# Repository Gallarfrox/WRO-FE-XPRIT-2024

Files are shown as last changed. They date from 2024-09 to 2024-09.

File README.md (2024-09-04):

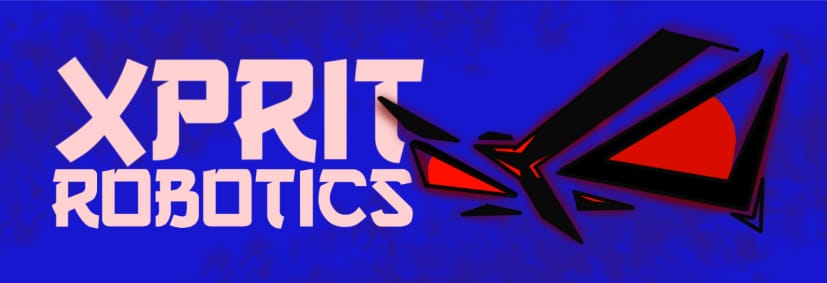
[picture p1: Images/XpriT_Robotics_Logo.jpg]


## Introduction
We are a team from Argentina participating in the Future Engineer Category at the World Robot Olympiad (WRO). Our team, XpriT Robotics, is composed of Franco Gallardo and Nahuel Cabaña.
## Index
* [**Contents**](#Contents)
* [**Chassis**](#Chassis)
* [**Power Supply**](#Power_Supply)
* [**Mobility And Direction**](#Mobility_And_Direction)
* [**Electronic Schematics**](#Schematic)
* [**Team Photos**](#Photos)
* [**Demonstration Videos**](#Demonstration_Videos)
## Contents
 * `3D Design` Contains 3D models of the robot in .STL format, ready for 3D printing.
 * `Edge Impulse` Includes obstacle images captured with the ESP32 Cam for training the machine learning model using Edge Impulse.
 * `SRC` Folder with all source codes and electronic schematics of the robot.
 * `Images` Robot photos and logos
 * `Youtube Channel` Videos demonstrating the robot navigating the circuit and avoiding obstacles.

## Chassis
 
 The Chassis of our robot are 3D printed Parts that were designed using SolidWorks and Tinkercad. All 3D models are in [**3D design Folder.**](https://github.com/Gallarfrox/WRO-FE-XPRIT-2024/tree/8289e319c8ed50b18eef6a841f7b57f9364190d7/3D%20Desings)
## Power Supply

The power supply utilized is a 370mAh 11.1V Li-Po battery. Additionally, we employ an LM7805 voltage regulator to stabilize the power supplied to our boards and microcontrollers.
## Mobility And Direction

To control direction, 
Our robot is designed with one DC motor and a single servo motor, chosen for their ease of replacement in Argentina also for its easy implementation. We use a custom 3D-printed part to enhance the steering of the front wheels, using the Ackerman Method for optimal maneuverability. The two wheels are directly attached to the DC motor, creating a compact and agile design. The robot follows the circuit’s external walls, ensuring an optimal turning radius and quick response time.
## Electronic Schematics

Our Electronic Schematics and Codes we use are in [**SRC folder.**](https://github.com/Gallarfrox/WRO-FE-XPRIT-2024/tree/fe686a653da6ce5ed55e57e9bf3dd3e55d9c889c/SRC)
## Team Photos

### Photo:
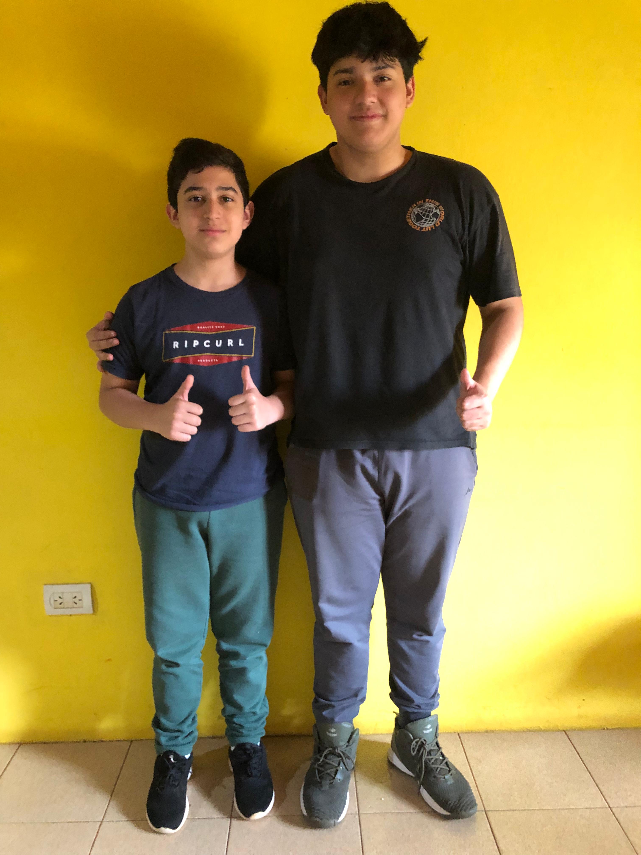
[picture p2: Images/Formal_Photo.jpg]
OPhoto

We have a funny photo in [**Images Folder**](https://github.com/Gallarfrox/WRO-FE-XPRIT-2024/tree/f97b17c5f60459615c8f3205b750cb3410c85aa1/Images)

## Demonstration Videos

Vist to [**this youtube channel**](https://youtube.com/@xprit_robotics?si=dhm_ktdyuf9bD-lI) to see demostration videos of the robot working on the circuit

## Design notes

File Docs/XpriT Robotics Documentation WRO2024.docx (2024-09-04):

# WORLD ROBOT OLYMPIAD 2024

# 2018

Future Engiener

Participants: Cabaña Nahuel, Gallardo Franco

Mentor: Aguirre Franco

Country: Argentina

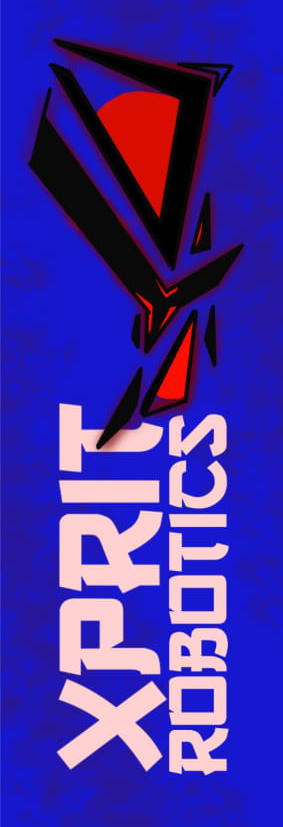
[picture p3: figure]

## Mobility Management

In alignment with the competition regulations, our robot is designed with precision, utilizing one DC motor and a single servo motor. To optimize the steering system, we have ingeniously incorporated a custom 3D-printed component that facilitates the turning of both front wheels, enabling smooth transitions from left to right. This steering mechanism, while straightforward in its design, proves to be highly effective and reliable for the robot's maneuverability.

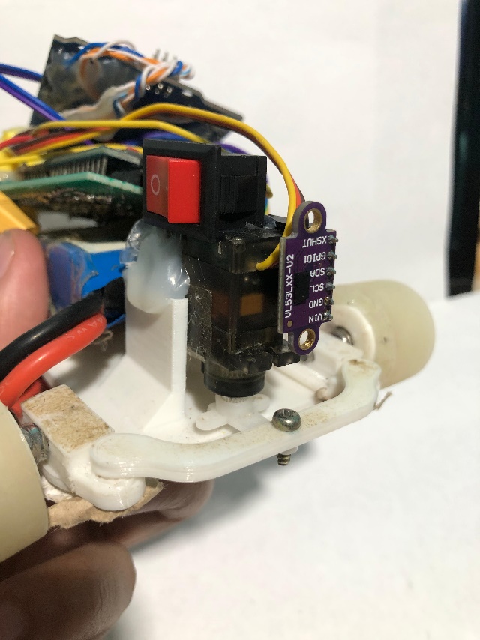
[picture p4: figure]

The DC motor is strategically mounted to ensure maximum efficiency. We've directly attached two wheels to it, achieving a streamlined and compact build. This not only minimizes the robot's overall size but also enhances its agility and responsiveness. The DC motor is critical in providing the essential forward and backward movements, making the robot versatile and well-suited for various challenges posed by the competition.

## Power and Sense Management

We power our robot using a 7V 2000mAh Li-Po battery, which efficiently drives both the logic components and the DC motors. Li-Po (Lithium-Polymer) batteries are particularly well-suited for robotics due to their lightweight design and high energy density, offering an excellent balance between power and portability. This allows the robot to maintain peak performance without adding unnecessary weight, which is crucial in competitive environments where every gram counts.

In terms of sensor technology, our robot is equipped with three CJVL53L0XV2 sensors, which play a critical role in ensuring precise and rapid wall distance detection. These sensors are capable of measuring distances up to 2 meters with millimeter-level accuracy, providing reliable data that allows our robot to navigate its environment with exceptional precision.

The high resolution of these sensors ensures that even the smallest deviations from the intended path are detected and corrected in real-time, enhancing the robot’s ability to respond to dynamic conditions and maintain optimal performance throughout the competition.

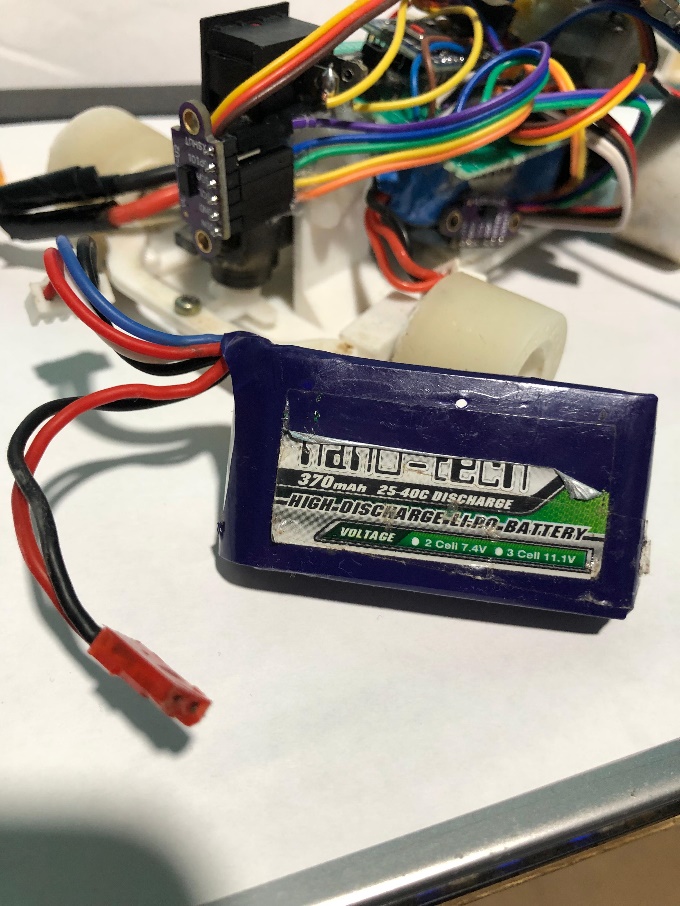
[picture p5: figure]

## Obstacle Management

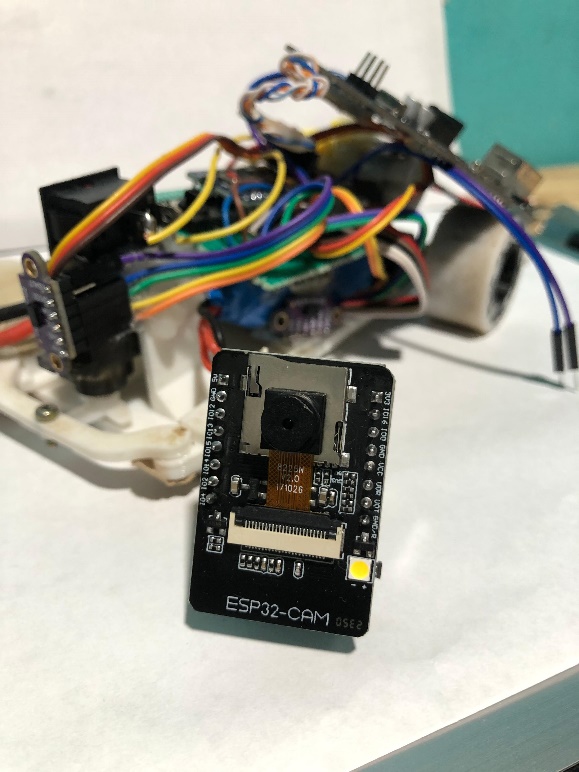
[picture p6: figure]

To detect colors and obstacles, we utilize an ESP32 camera, a versatile board that excels not only in capturing images but also in processing them using artificial intelligence (AI). This capability makes the ESP32 camera particularly effective for real-time obstacle avoidance, as it enables the robot to make instantaneous decisions based on its environment. The onboard processing power of the ESP32 allows it to handle complex computations directly on the device, thereby eliminating the latency associated with sending data to an external server. This local processing capability ensures faster and more efficient responses, which is critical in dynamic and fast-paced competition settings where every millisecond counts.

In order to optimize the performance of the ESP32 camera, we train its system using Edge Impulse, a cutting-edge platform that streamlines the creation and training of custom machine learning models. Edge Impulse allows us to develop models tailored to our specific needs, enabling the camera to recognize and differentiate between a wide range of colors and objects with high accuracy. By leveraging this platform, we significantly enhance the robot's ability to identify and avoid obstacles in real-time, ensuring that it can navigate complex environments with precision and reliability. This integration of advanced AI and machine learning techniques into our robot's sensory system represents a significant advantage, providing it with the intelligence necessary to adapt to changing conditions and make informed decisions on the fly.

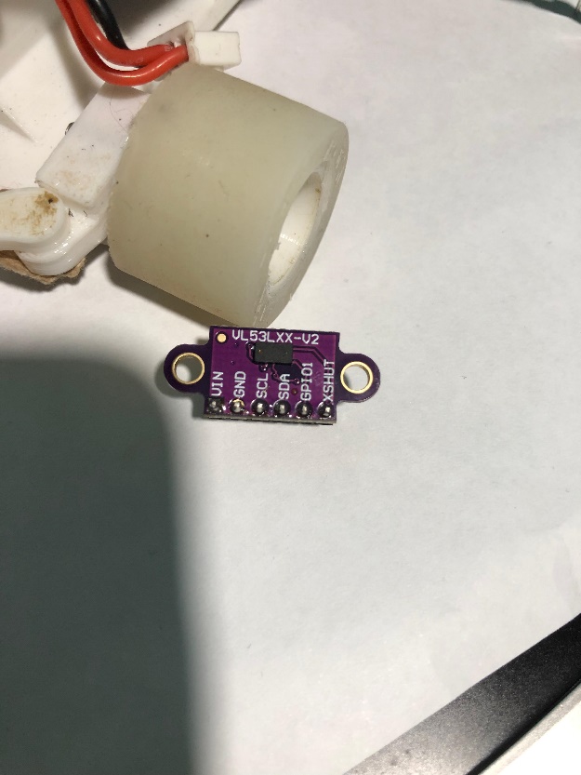
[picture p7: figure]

GitHub

We use GitHub as our version control system, which allows us to efficiently manage and track changes in our code. Additionally, we use it for file sharing among team members and to keep our project documentation up to date, ensuring everyone has access to the latest information and resources.

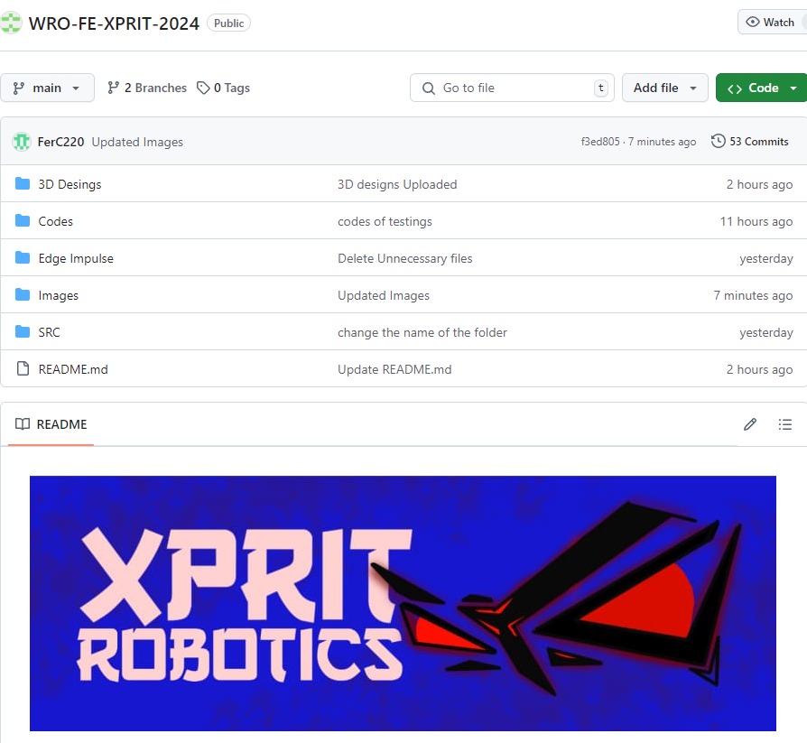
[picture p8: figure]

Engineering Factor

The robot's chassis and all of its mechanisms were designed and 3D-printed by us. The steering system was designed using the Ackerman method. The control board and its circuit were also designed, soldered, and engineered by us.

We use two ESP32-C3 Super Mini controllers: one as the master, which reads sensors and performs calculations to control the robot, and a second as the slave, which receives movement commands. This second controller manages the DC motor and the servo motor based on the information sent by the master.

Additionally, we use CJVL53L0XV2 sensors to provide the robot with spatial awareness, allowing it to detect its surroundings and complete the challenge.

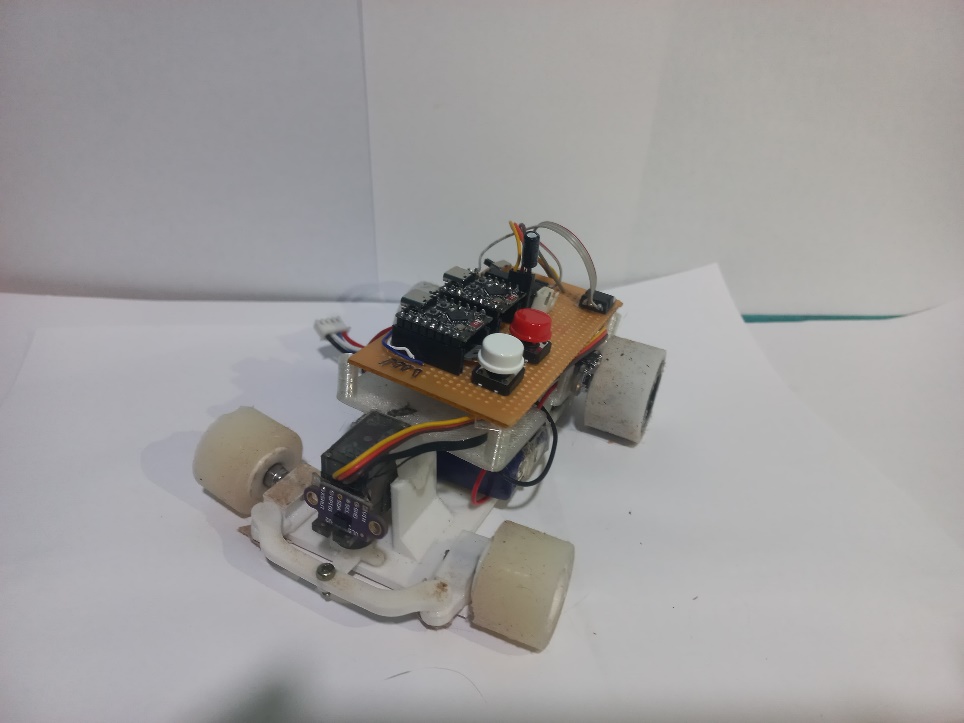
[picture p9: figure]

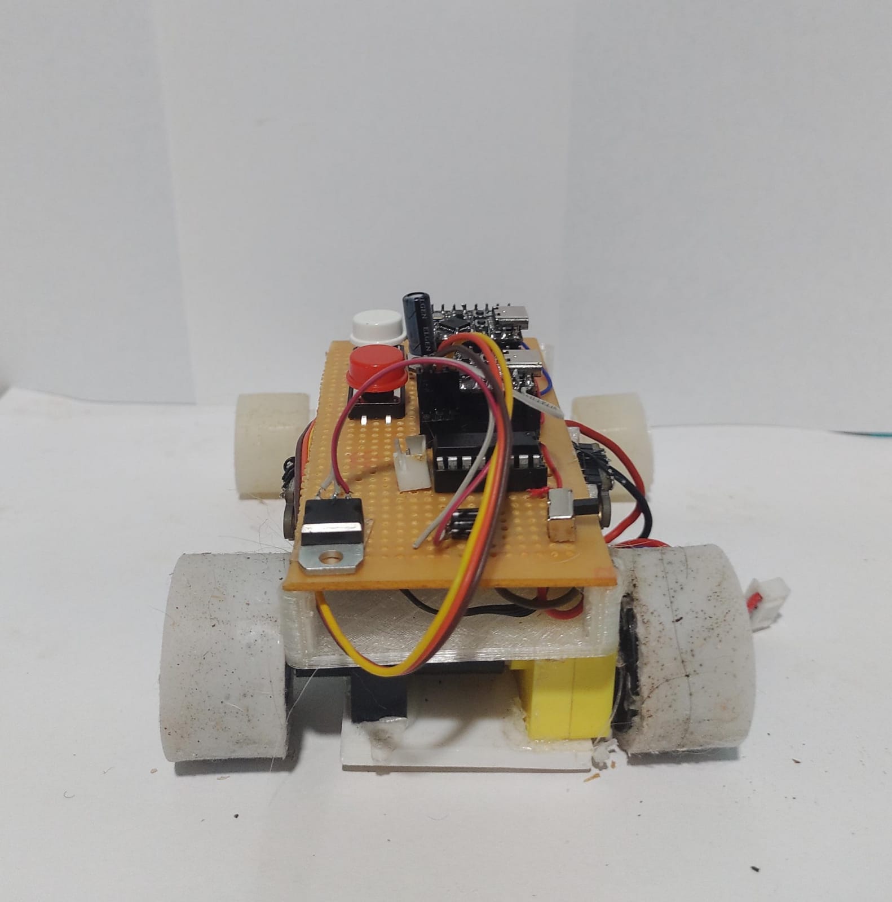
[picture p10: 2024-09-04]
Images/Back_side_Robot.jpg

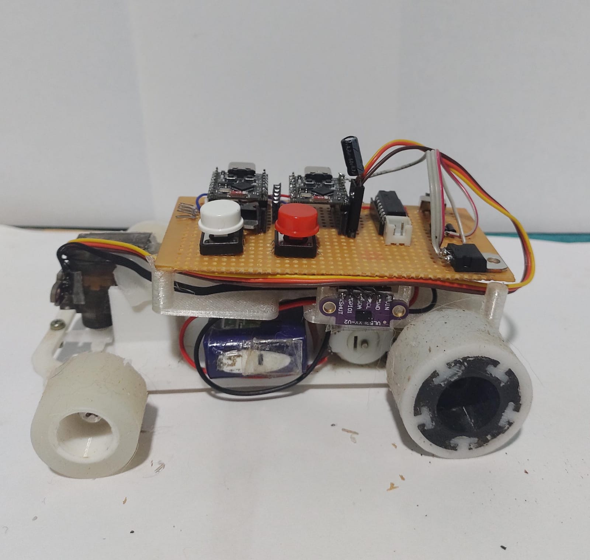
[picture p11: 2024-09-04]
Images/Left_side_robot.jpg

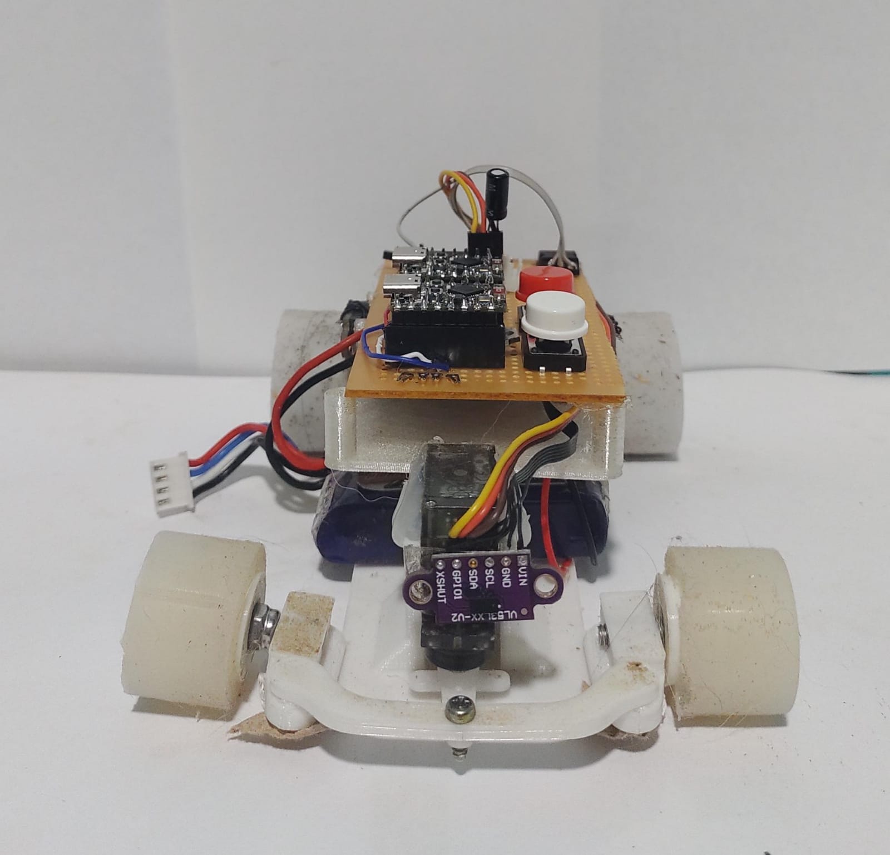
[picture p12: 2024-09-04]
Images/Front_side_Robot.jpg

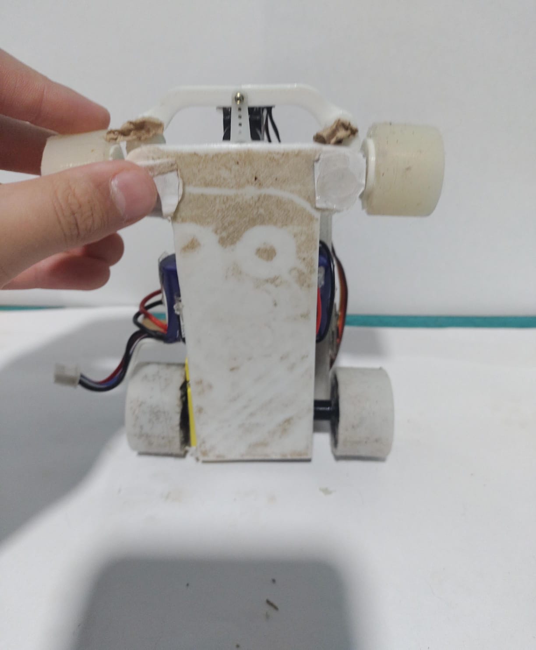
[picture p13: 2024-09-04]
Images/Bottom_side_robot.jpg

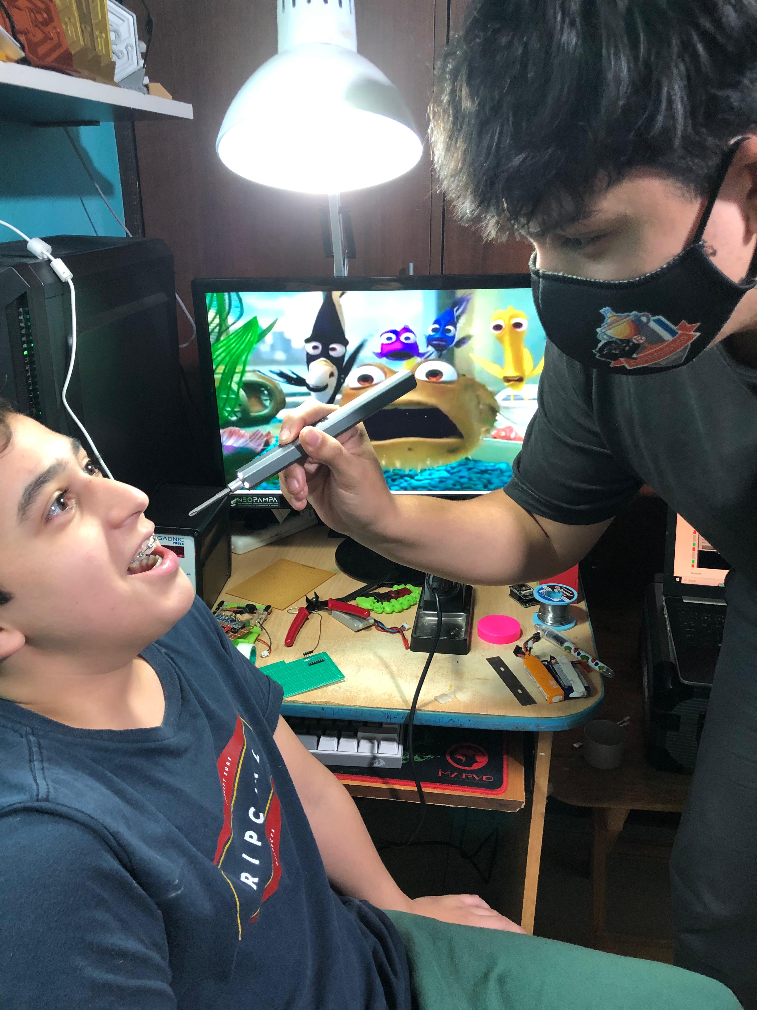
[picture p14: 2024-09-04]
Images/Funny_Photo.jpg

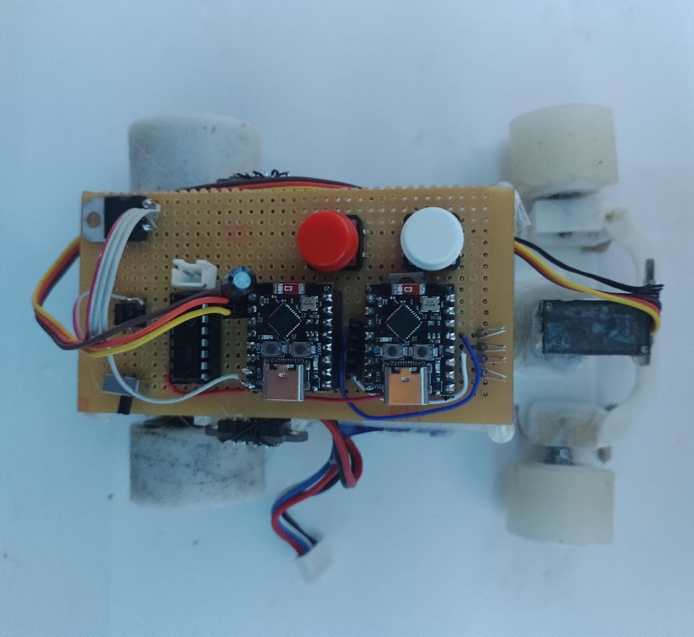
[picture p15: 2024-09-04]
Images/Top_side_robot.jpg

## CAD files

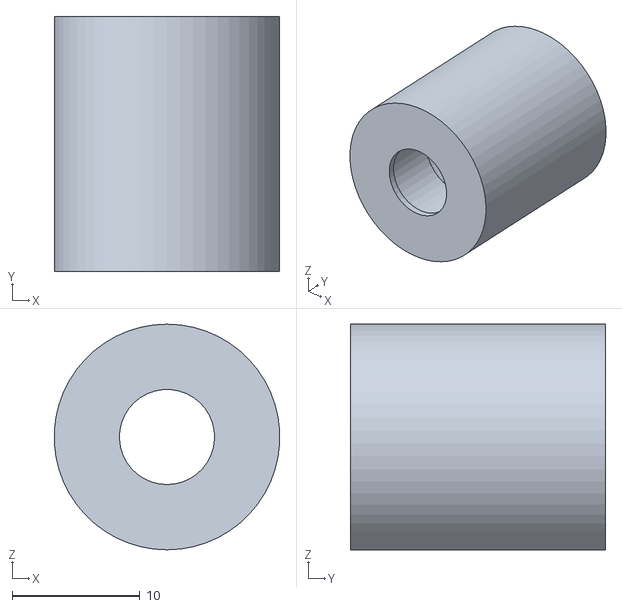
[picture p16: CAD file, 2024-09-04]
3D Desings/Front_Wheel.STL
17.7 x 20.0 x 17.7

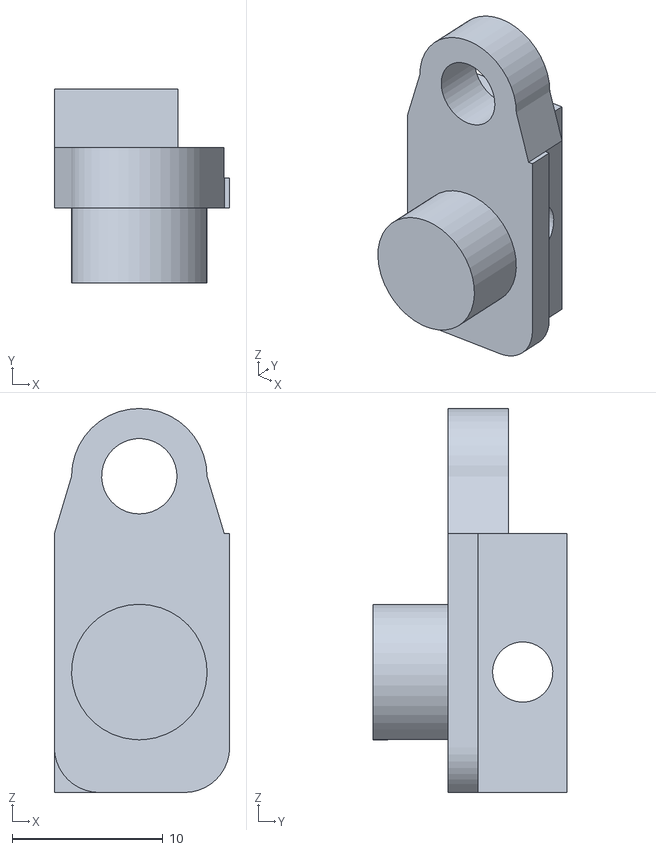
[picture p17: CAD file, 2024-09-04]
3D Desings/Steering_Wheel_Axis_WRO.STL
11.6 x 12.9 x 25.5

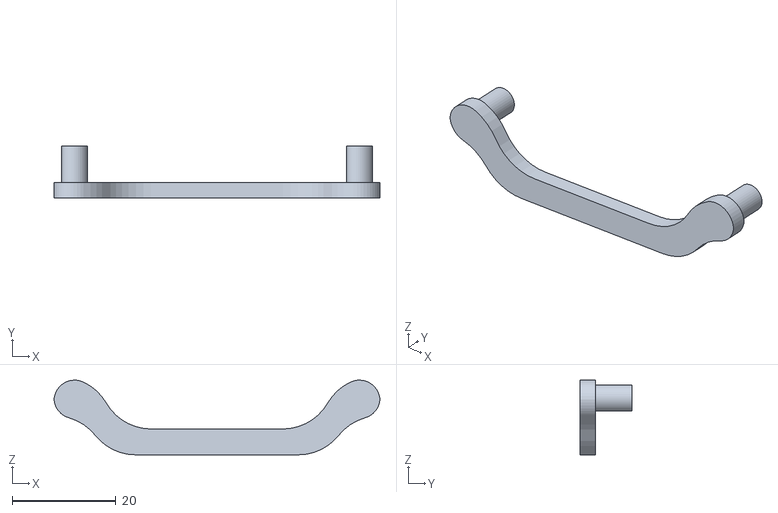
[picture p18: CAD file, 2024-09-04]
3D Desings/Steering_arm_WRO.STL
63.0 x 10.0 x 14.4

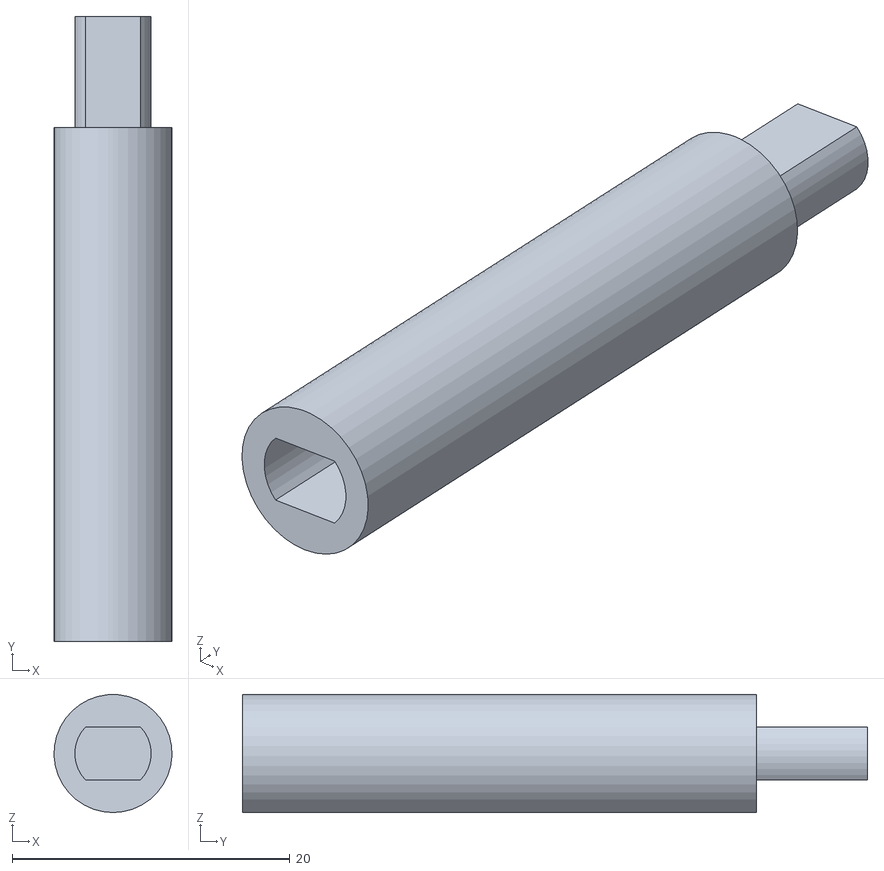
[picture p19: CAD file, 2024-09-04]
3D Desings/Extended_Axis_WRO.STL
8.49 x 45.0 x 8.50

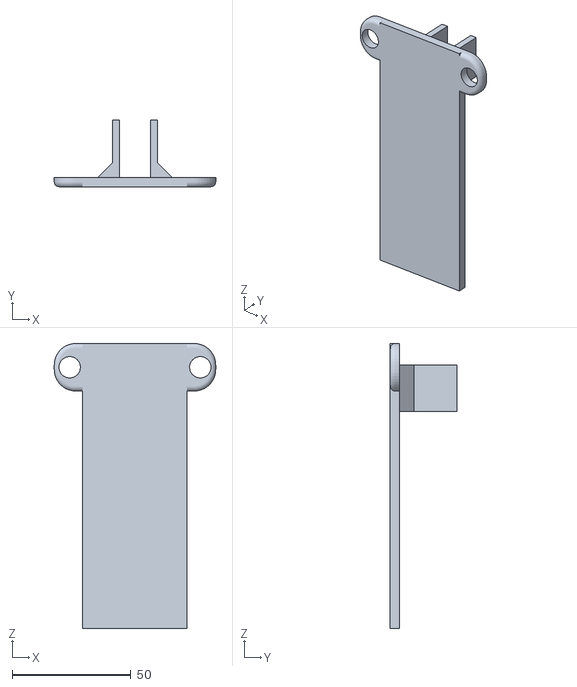
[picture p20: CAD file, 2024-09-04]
3D Desings/chasis_WRO.STL
68.0 x 28.0 x 120.0

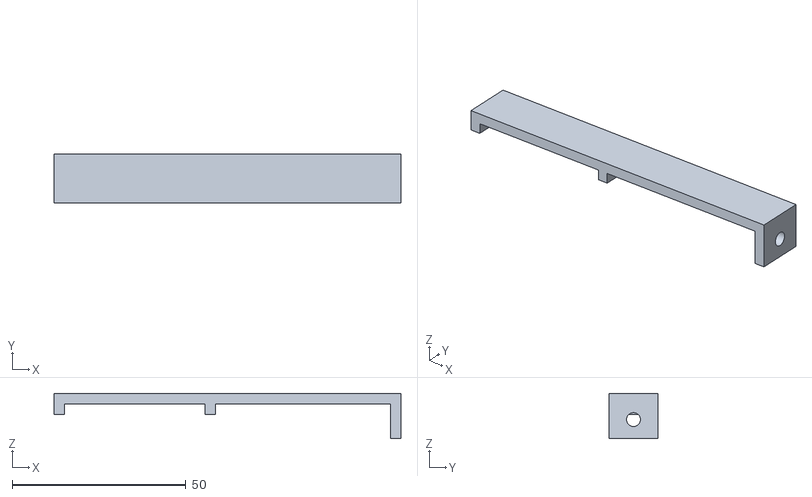
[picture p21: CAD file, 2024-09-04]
3D Desings/soporte camara.STL
100.0 x 14.0 x 13.0

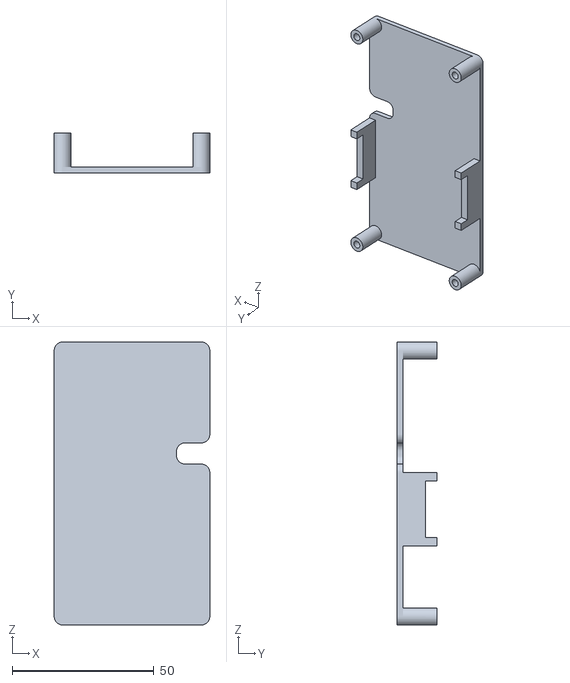
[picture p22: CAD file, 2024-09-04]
3D Desings/soporte_Placa_wro.STL
55.0 x 14.0 x 100.0

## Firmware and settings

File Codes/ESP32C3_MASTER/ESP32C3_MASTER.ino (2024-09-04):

#include <Wire.h>
#include <VL53L0X.h>

// Definir direcciones I2C
#define VL53L0X_ADDRESS 0x29 // Dirección I2C por defecto del VL53L0X
#define ESP32_SLAVE_ADDRESS 0x08 // Dirección I2C del ESP32 esclavo

VL53L0X sensor;

//Pin Declarations
#define buttonSO 0
#define buttonCO 1



//Adjustable Variables    This variables are maked to adjust some parameters of the robot
int TurnDistance = 300; //this variable affect the distance to turn, reading how much nerby to the wall are the robot
int servoAngle = 90;   //This variable is the Servo Position
int motorSpeed = 250;  //This variable is the Motor Velocity}



//Non-Adjustable Variables    this are variables who are used to Adjust things automatically
int wallSen = 0;
int TurnDirection = 0;
int Mode = 0;

void setup() {
  Serial.begin(115200);

  //--------------- PinMode Declarations ---------------//

  pinMode(buttonSO, INPUT_PULLUP);


  Wire.begin(); // Pines SDA y SCL en el ESP32-C3 maestro
  // Comprobar la conexión con el ESP32 esclavo
  Wire.beginTransmission(ESP32_SLAVE_ADDRESS);
  if (Wire.endTransmission() == 0) {
    Serial.println("Conexión con ESP32 esclavo exitosa.");
  } else {
    Serial.println("No se pudo conectar con el ESP32 esclavo.");
  }

  // Inicializar el sensor VL53L0X
  Wire.beginTransmission(VL53L0X_ADDRESS);
  if (Wire.endTransmission() == 0) {
    sensor.setTimeout(500);
    if (!sensor.init(true)) {
      Serial.println("Fallo en la inicialización del sensor VL53L0X");
      while (1);
    }
    sensor.startContinuous();
  } else {
    Serial.println("Sensor VL53L0X no encontrado.");
  }


}

void loop() {
  // Paso 1: Lectura del sensor VL53L0X
  int distance = -1;
  Wire.beginTransmission(VL53L0X_ADDRESS);
  if (Wire.endTransmission() == 0) {
    distance = sensor.readRangeContinuousMillimeters();
    if (!sensor.timeoutOccurred()) {
      Serial.print("Distancia medida: ");
      Serial.print(distance);
      Serial.println(" mm");
    } else {
      Serial.println("Timeout en el sensor VL53L0X");
    }
  }

  // Esperar un momento para evitar choque de datos
  delay(10);
  //
  //  servoAngle = map(distance, 30, 500, 10, 150);
  //  if (servoAngle < 10) servoAngle = 10;
  //  if (servoAngle > 150) servoAngle = 150;
  //

  // Paso 2: Enviar datos al ESP32 esclavo
  String mensaje = String(servoAngle) + "," + String(motorSpeed);
  Wire.beginTransmission(ESP32_SLAVE_ADDRESS);
  Wire.print(mensaje);
  Wire.endTransmission();

  Serial.print("Mensaje enviado al esclavo: "); Serial.println(mensaje);

  // Esperar otro momento antes de volver al sensor
  delay(10); // Esperar 10 milisegundos antes de repetir el ciclo
}


void selLado (int sen1, int sen2, int sen3) { //the order of Sensors are Right, Left, Middle :)
  if ((buttonSO == LOW) && (Mode == 0) && (buttonCO == HIGH)) {
    Mode = 1;
  } else if ((buttonSO == HIGH) && (Mode == 0) && (buttonCO == LOW)) {
    Mode = 2;
  }

  if (Mode == 1) {

    if ((buttonSO == LOW) && (sen1 < 100) && (sen2 > 100)) {
      TurnDirection = 1;
      if (TurnDirection == 1) {
        if ((wallSen == 0) && (sen3 > TurnDistance)) {
          motorSpeed = 250;
          servoAngle = 90;
        } else if ((sen3 < TurnDistance)) {
          wallSen = 1;
          motorSpeed = 250;
          servoAngle = 45;
          delay(3000);
        }
        if ((wallSen == 1) && (sen3 > TurnDistance)) {
          servoAngle = map(sen1, 30, 500, 45, 135);
          if (servoAngle < 45) servoAngle = 45;
          if (servoAngle > 135) servoAngle = 135;
        }
      }
    }
    if ((buttonSO == LOW) && (sen2 < 100) && (sen1 > 100)) {
      TurnDirection = 2;
    }
    if (TurnDirection == 2) {
      if ((wallSen == 0) && (sen3 > TurnDistance)) {
        motorSpeed = 250;
        servoAngle = 90;
      } else if ((sen3 < TurnDistance)) {
        wallSen = 1;
        motorSpeed = 250;
        servoAngle = 135;
        delay(3000);
      }
      if ((wallSen == 1) && (sen3 > TurnDistance)) {
        servoAngle = map(sen2, 30, 500, 135, 45);
        if (servoAngle < 45) servoAngle = 45;
        if (servoAngle > 135) servoAngle = 135;
      }
    }
  }
  if (Mode == 2) {

  }


}

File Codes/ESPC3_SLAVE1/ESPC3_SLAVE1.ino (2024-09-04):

#include <Servo.h>

#include <Wire.h>

Servo myservo = Servo();

int servoAngle = 0;
int motorSpeed = 0;


#define PWM 4
#define m1 3
#define m2 2


const int servoPin1 = 1;

void setup() {
  pinMode(m1, OUTPUT);
  pinMode(m2, OUTPUT);
  pinMode(PWM, OUTPUT);
  delay(200);
  Wire.begin(0x08);              // Configura el esclavo I2C con la dirección 0x08
  Wire.onReceive(receiveEvent);  // Asocia la función de recepción de datos
  Serial.begin(115200);
}

void loop() {
  // Aquí podrías agregar el código para controlar el servomotor y el motor utilizando los valores recibidos
  Serial.print("Ángulo del servomotor: ");
  Serial.println(servoAngle);
  Serial.print("Velocidad del motor: ");
  Serial.println(motorSpeed); 
  
  delay(10); // Espera para evitar bloquear el programa

  Motor(motorSpeed);
  myservo.write(servoPin1, servoAngle, 150, 0.0);
  
}

void receiveEvent(int howMany) {
  String receivedData = "";
  while (Wire.available()) {         // Lee todos los bytes recibidos
    char c = Wire.read();            // Lee un byte
    receivedData += c;               // Agrega el byte a la cadena de datos recibidos
  }

  // Procesa la cadena recibida
  if (receivedData.length() > 0) {
    int delimiterIndex = receivedData.indexOf(','); // Encuentra el delimitador
    
    if (delimiterIndex != -1) {
      servoAngle = receivedData.substring(0, delimiterIndex).toInt(); // Extrae y convierte el ángulo
      motorSpeed = receivedData.substring(delimiterIndex + 1).toInt(); // Extrae y convierte la velocidad
    }
  }
}

void Motor(int vel){
  if (vel < 0){
    digitalWrite(m1, LOW);
    digitalWrite(m2, HIGH);
    analogWrite(PWM,abs(vel));
  }else{
    digitalWrite(m1, HIGH);
    digitalWrite(m2, LOW);
    analogWrite(PWM,abs(vel));
  }
}

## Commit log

2024-09-03 Create ESPC3_SLAVE1.ino
    in this commit we create a code for the ESP32 C3 SLAVE
2024-09-03 we create a carpet for designs
    [Soporte WRO.stl]
2024-09-03 we translate the name of the carpet
    [Soporte WRO.stl]
2024-09-03 We eliminate some Images and Added the Master code
    [Soporte WRO.stl]
2024-09-04 Modify some codes like Master and Slave ESP32
2024-09-04 3D designs Uploaded
    [ESP32 Cam Support.stl, Extended_Axis_WRO.STL, Front_Wheel.STL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]
